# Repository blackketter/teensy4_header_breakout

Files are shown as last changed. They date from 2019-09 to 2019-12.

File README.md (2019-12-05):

A breakout board for the PJRC.com Teensy 4.0 board that is soldered directly to the bottom of the Teensy board via castellated solder points and two parallel 2x14 0.1" headers for connection.

There are companion boards that can attach to the outside pins and provide:

- [Micro SD Slot Sidecar](https://github.com/blackketter/teensy4_sd_breakout)
- [USB Host Sidecar](https://github.com/blackketter/teensy4_usb_host_breakout)
- [ESP32 WiFi & Bluetooth Sidecar](https://github.com/blackketter/teensy4_esp32_breakout)

Designed in KiCad.

Current design, avaiable at [OSHPark](https://oshpark.com/shared_projects/tZbsjC0v):

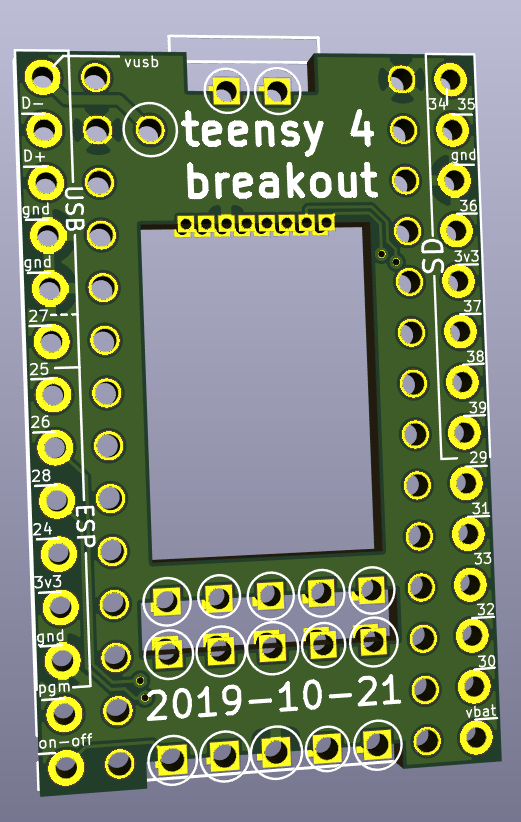
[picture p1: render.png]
breakout render

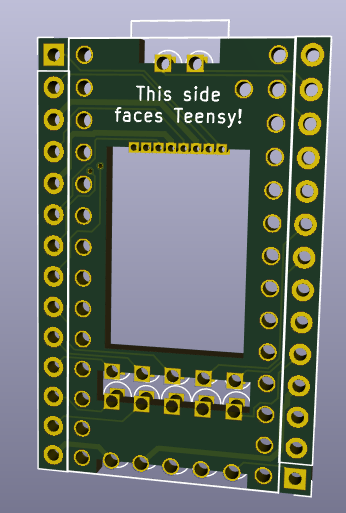
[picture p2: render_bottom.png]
breakout render bottom


Previous prototype:

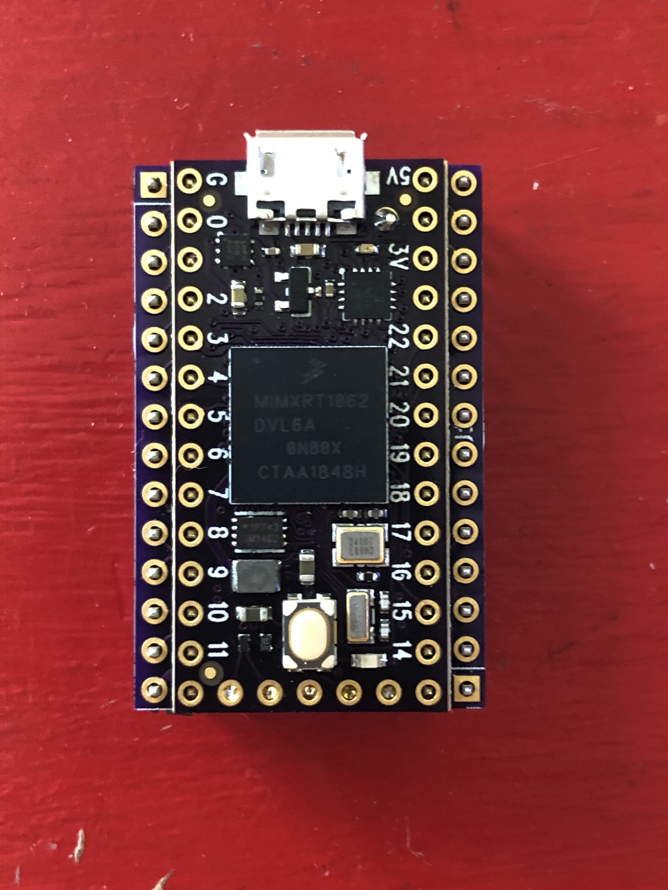
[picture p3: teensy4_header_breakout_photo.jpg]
breakout photo

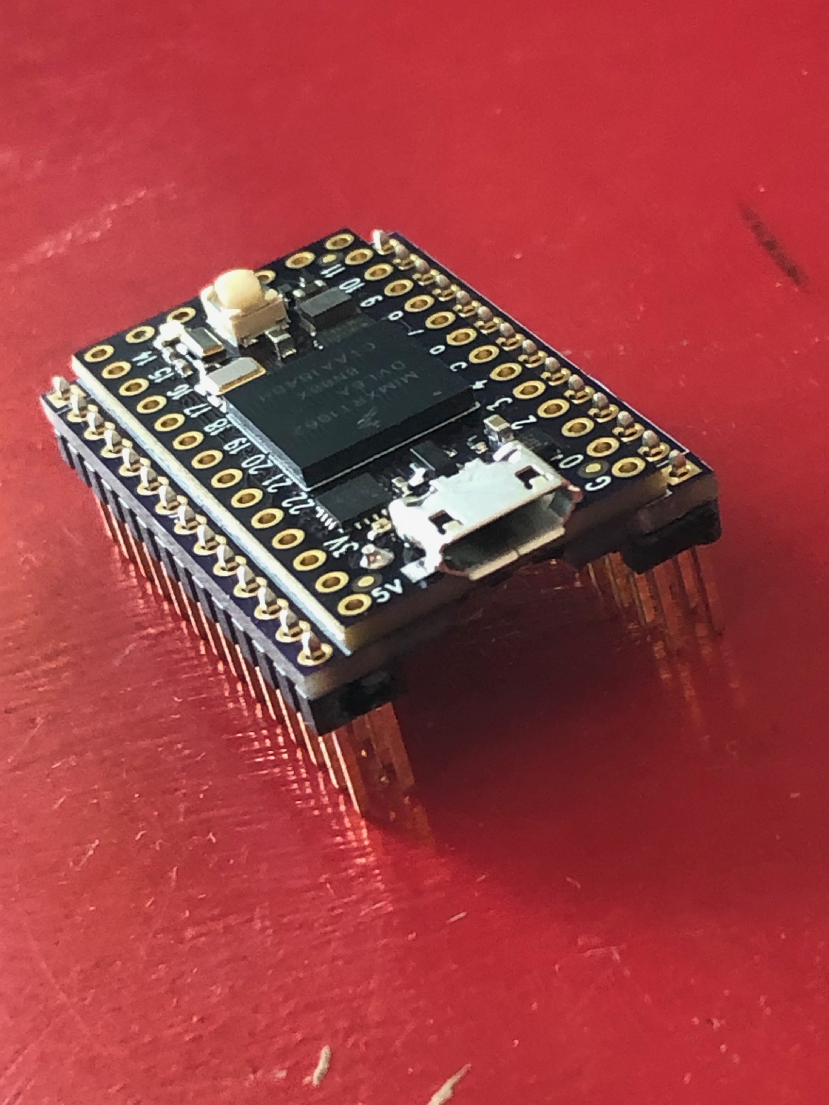
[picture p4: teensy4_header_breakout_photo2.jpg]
breakout photo


Notes:

- If you need to cut the trace between VIN and VUSB, do it before attaching board.
- You should be able to use one of [these](https://www.pjrc.com/store/cable_usb_host_t36.html) cables connected to pins 1-5 on the right side for a basic USB host connection (albeit without power management and protection). For a better protected solution see [this USB sidecar](https://github.com/blackketter/teensy4_usb_host_breakout)
- Make sure to solder all the pins marked with circles.  You may need a bit of wire to make the connection on the Teensy VUSB pin.
- When soldering the Teensy pins, make sure you give them plenty of solder, heat and time for the solder to flow to the other side.  And make sure you test the connections with a continuity tester for opens ans shorts
- A thinner PCB will make it easier to solder. (Caution: OSHPark 0.8mm thick boards are not being made reliably.  Better to use 1.6mm process.)
- Todo: Reduce size of larger internal cutout.

Left Side Pinout:

1. 34/SD DAT1
2. 35/SD DAT0
3. GND
4. 36/SD CLK
5. 3.3V
6. 37/SD CMD
7. 38/SD DAT3
8. 39/SD DAT2
9. 29
10. 31
11. 33
12. 32
13. 30
14. VBAT

Right Side Pinout:

1. VUSB
2. USB Host D-
3. USB Host D+
4. GND
5. GND
6. 27
7. 25
8. 26
9. 28
10. 24
11. 3V3
12. GND
13. Program
14. On/Off

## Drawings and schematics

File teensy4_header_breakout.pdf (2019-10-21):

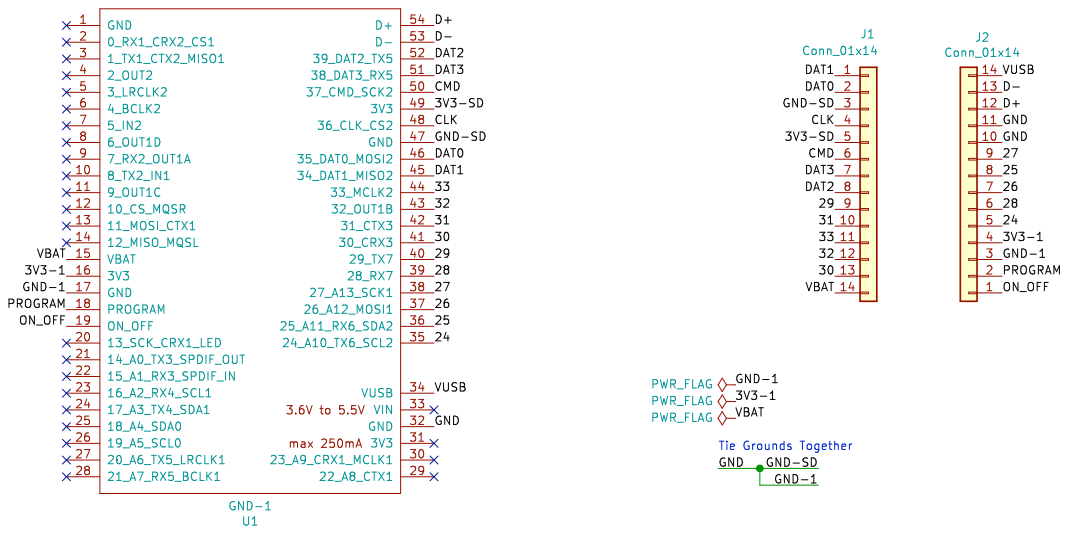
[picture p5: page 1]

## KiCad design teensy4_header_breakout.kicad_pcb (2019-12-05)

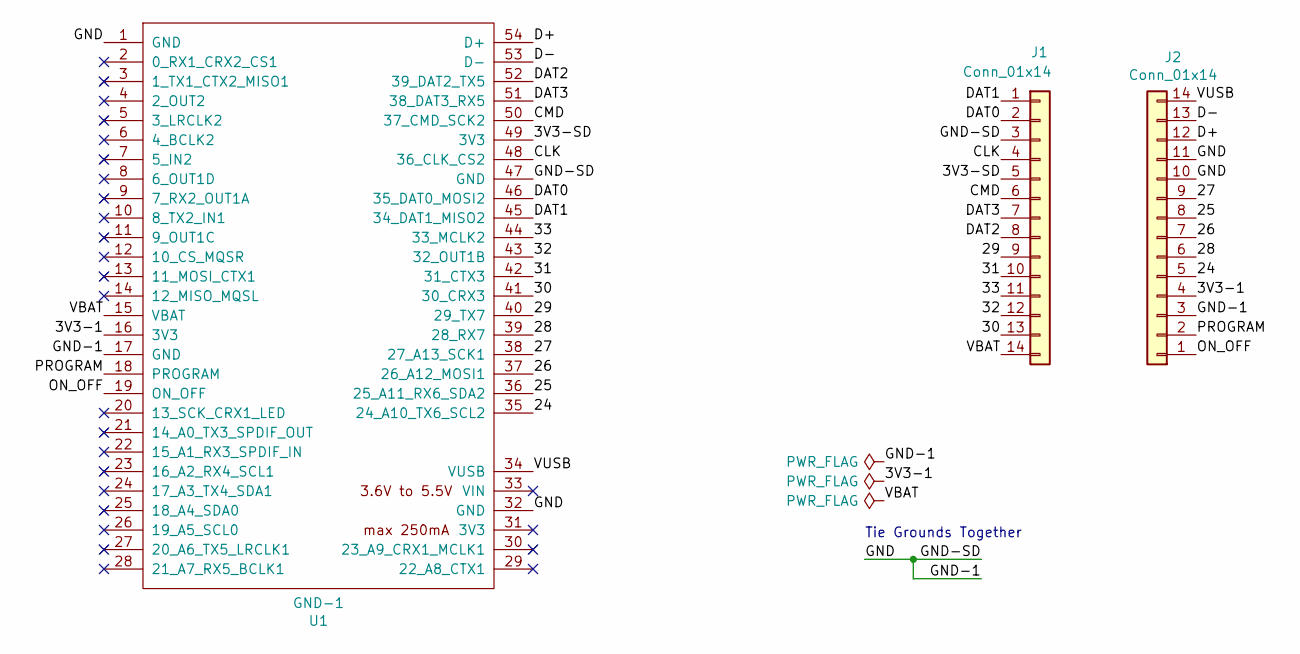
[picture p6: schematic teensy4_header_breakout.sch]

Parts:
J1, J2: Conn_01x14; PinHeader_1x14_P2.54mm_Vertical
U1: GND-1; Teensy40_SMT

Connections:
/3V3-1: J2.4, U1.16 (3V3)
/3V3-SD: J1.5, U1.49 (3V3)
/24: J2.5, U1.35 (24_A10_TX6_SCL2)
/25: J2.8, U1.36 (25_A11_RX6_SDA2)
/26: J2.7, U1.37 (26_A12_MOSI1)
/27: J2.9, U1.38 (27_A13_SCK1)
/28: J2.6, U1.39 (28_RX7)
/29: J1.9, U1.40 (29_TX7)
/30: J1.13, U1.41 (30_CRX3)
/31: J1.10, U1.42 (31_CTX3)
/32: J1.12, U1.43 (32_OUT1B)
/33: J1.11, U1.44 (33_MCLK2)
/CLK: J1.4, U1.48 (36_CLK_CS2)
/CMD: J1.6, U1.50 (37_CMD_SCK2)
/D+: J2.12, U1.54 (D+)
/D-: J2.13, U1.53 (D-)
/DAT0: J1.2, U1.46 (35_DAT0_MOSI2)
/DAT1: J1.1, U1.45 (34_DAT1_MISO2)
/DAT2: J1.8, U1.52 (39_DAT2_TX5)
/DAT3: J1.7, U1.51 (38_DAT3_RX5)
/GND: J1.3, J2.3, J2.10, J2.11, U1.1 (GND), U1.17 (GND), U1.32 (GND), U1.47 (GND)
/ON_OFF: J2.1, U1.19 (ON_OFF)
/PROGRAM: J2.2, U1.18 (PROGRAM)
/VBAT: J1.14, U1.15 (VBAT)
/VUSB: J2.14, U1.34 (VUSB)

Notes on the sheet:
Tie Grounds Together

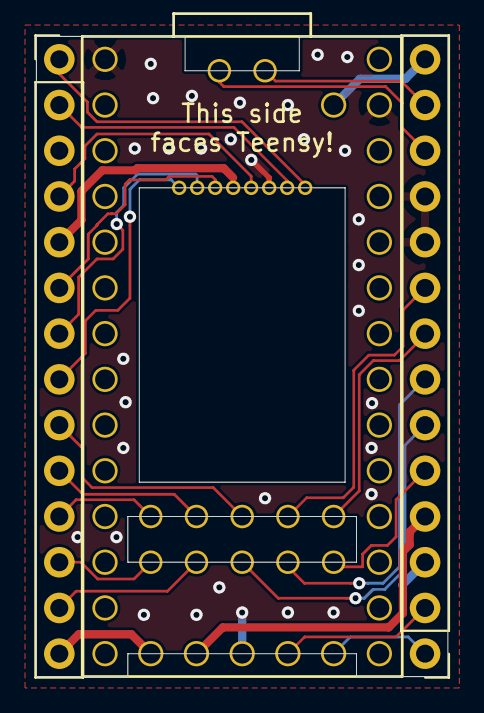
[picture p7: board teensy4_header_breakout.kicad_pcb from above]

Board: 2 copper layers, 22.9 x 35.6 mm, 3 parts (0 on the bottom side), 25 nets.

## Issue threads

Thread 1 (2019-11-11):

Half Hole Question

tinyboxxx, 2019-11-11:
Hi, great work, but I have few questions.

I asked few local PCB manufacturer, they charge these half holes very expensive, ￥150 to 300 RMB (more than 25 USD). When without half holes, it only cost 5 to 25 RMB.

So why OSH Park can do it in reasonable price? Should I cutting it myself?

Thanks.

blackketter, 2019-12-05:
Sorry, just saw this question now.  OSHPark doesn't guarantee the hole castellations, so the feature isn't officially supported.  That said, the 1.6mm thickness boards seem to work ok, but the 0.8mm process at OSHPark have not worked well.
Getting boards made this way (especially with internal cutouts) is harder and takes more time, that's why they are more expensive.  I suspect that the price could come down if they were made in high enough volume.

Closed 2019-12-05.

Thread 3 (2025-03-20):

I tried making my own but doesn’t work

propeller3D, 2025-03-20:
Hello I tried to integrate this into a custom pcb but it doesn’t seem to be working.

Any chance you could take a look at it and see what I did wrong?

I made a thread at jlcpcb:

https://forum.pjrc.com/index.php?threads/break-out-the-usb-on-teensy-4-to-my-custom-pcb-problem.76716/

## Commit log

2019-09-19 Updated two unused pins to GND to allow a basic USB cable to be attached.
    [teensy4_header_breakout.kicad_pcb, teensy4_header_breakout.sch]
2019-09-19 Update date on silkscreen
    [teensy4_header_breakout.kicad_pcb]
2019-09-20 Add schematic PDF
2019-09-24 Flip Teensy on schematic to be visually closer to actual pin layout.
    [teensy4_header_breakout.sch]
2019-10-04 Generated gerbers for order to AllPCB
    [teensy4_header_breakout-B_Cu.gbr, teensy4_header_breakout-B_Mask.gbr, teensy4_header_breakout-B_SilkS.gbr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]
2019-10-12 Update board with new labels and square pads
    [teensy4_header_breakout-B_Cu.gbr, teensy4_header_breakout-B_Mask.gbr, teensy4_header_breakout-B_SilkS.gbr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]
2019-10-20 Update readme, silkscreen and tweak outline
    [teensy4_header_breakout.kicad_pcb]
2019-10-21 Added ground plane and graphics for sidecars
    [teensy4_header_breakout.kicad_pcb, teensy4_header_breakout.sch]
2019-10-21 Fix date
    [teensy4_header_breakout.kicad_pcb]
2019-10-21 Update schematic
2019-10-21 Add gnd pin to plane
    [teensy4_header_breakout.kicad_pcb, teensy4_header_breakout.sch]
2019-10-21 add pin labels to silkscreen
    [teensy4_header_breakout.kicad_pcb]
2019-12-05 More ground plane, add todo
    [teensy4_header_breakout.kicad_pcb]
